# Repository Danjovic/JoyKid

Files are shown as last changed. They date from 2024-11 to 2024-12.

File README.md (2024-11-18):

# Joy Kid 

This project started as an exercise of passing and receiving parameters using CALL function, but evolved to a hardware prototype using a microcontroller that sends data through the MSX joystick port in order to emulate the MSX  [Sensor Kid](https://www.msx.org/wiki/Micomsoft_Sensor_Kid) Interface.

## Protocol
The circuit uses lightweight protocol that transfers sensor data using nibbles. The transfer is commanded by pin 8 (pulse) and the data transfer is paced by pin 7 (trigger B). Pin 6 (trigger A) is used both by the microcontroller to provide a 'ready' signal to the MSX and also to get PORT0/1 data. 

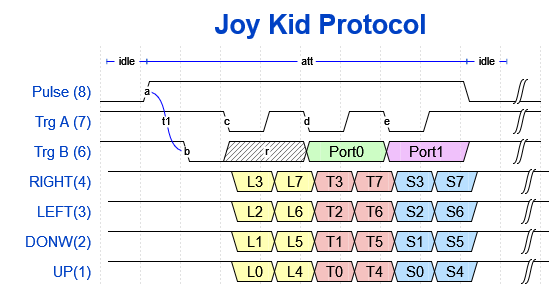
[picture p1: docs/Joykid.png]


### Waveform

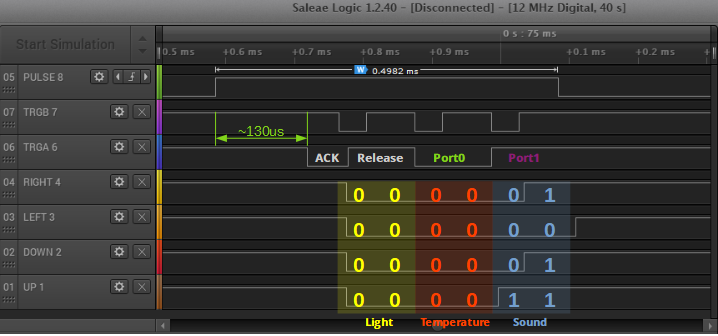
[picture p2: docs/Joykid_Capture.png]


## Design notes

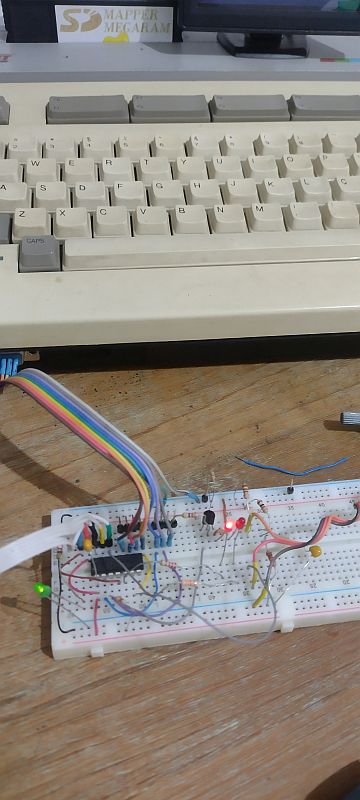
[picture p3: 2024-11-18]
docs/prototype0.jpg

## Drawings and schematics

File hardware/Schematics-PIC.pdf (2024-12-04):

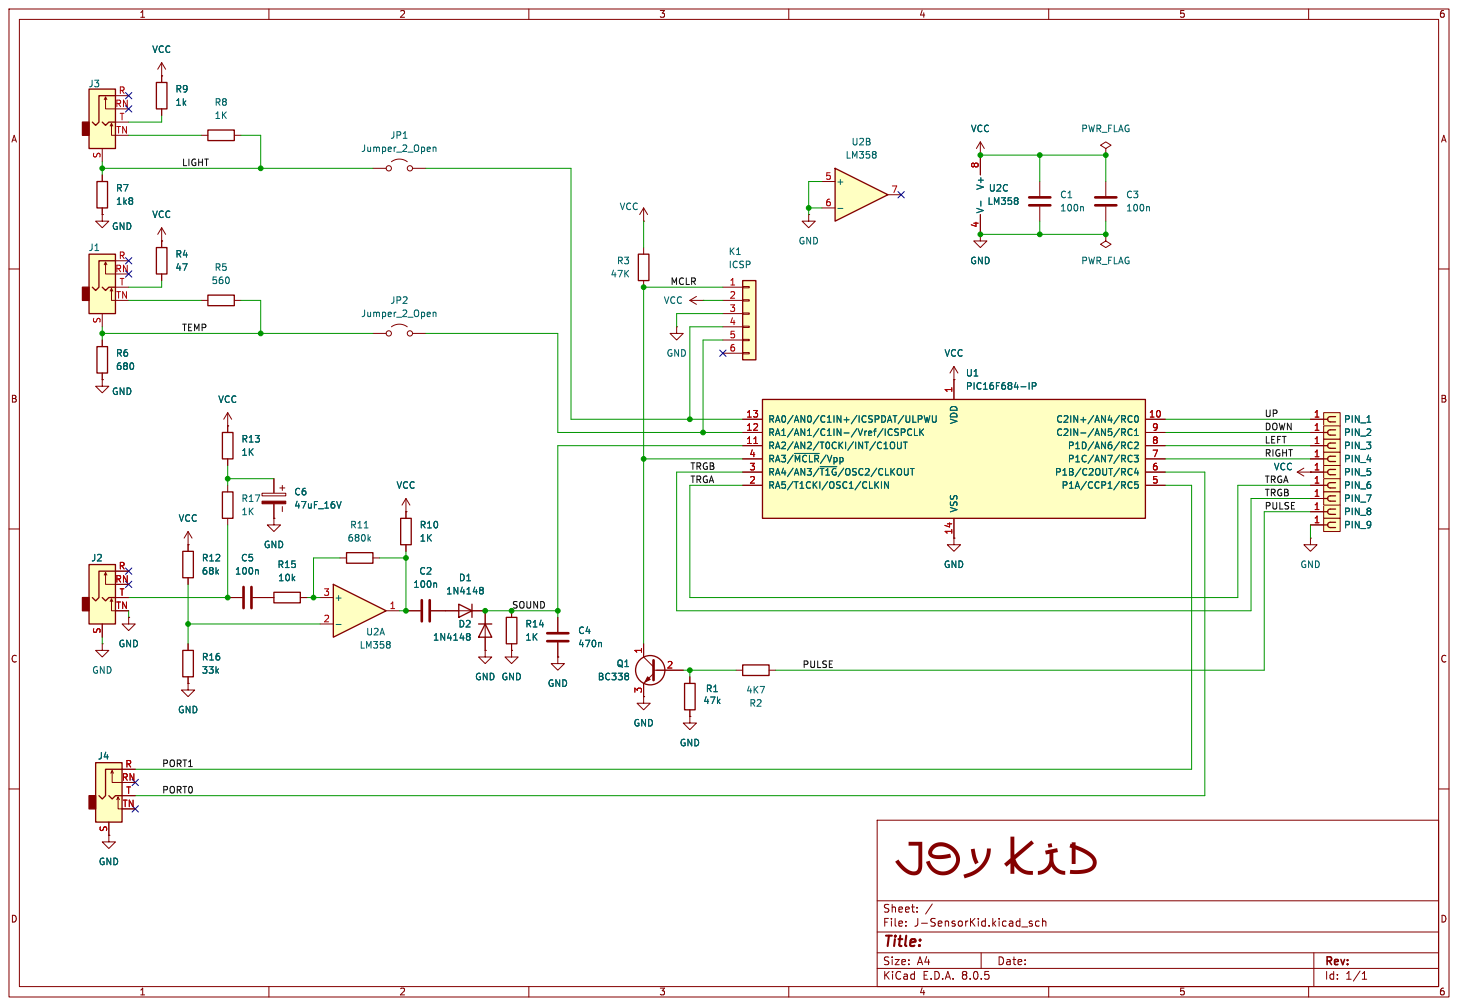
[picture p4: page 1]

1 C2IN+/AN4/RC0 10 RA2/AN2/T0CKI/INT/C1OUT 11 RA1/AN1/C1IN-/Vref/ICSPCLK 12 RA0/AN0/C1IN+/ICSPDAT/ULPWU 13 VSS 14 RA5/T1CKI/OSC1/CLKIN 2 RA4/AN3/~{T1G}/OSC2/CLKOUT 3 RA3/~{MCLR}/Vpp 4 P1A/CCP1/RC5 5 P1B/C2OUT/RC4 6 P1C/AN7/RC3 7 P1D/AN6/RC2 8 C2IN-/AN5/RC1 9 U1PIC16F684-IP GND GND
1K GND

1 C2IN+/AN4/RC0 10 RA2/AN2/T0CKI/INT/C1OUT 11 RA1/AN1/C1IN-/Vref/ICSPCLK 12 RA0/AN0/C1IN+/ICSPDAT/ULPWU 13 VSS 14 RA5/T1CKI/OSC1/CLKIN 2 RA4/AN3/~{T1G}/OSC2/CLKOUT 3 RA3/~{MCLR}/Vpp 4 P1A/CCP1/RC5 5 P1B/C2OUT/RC4 6 P1C/AN7/RC3 7 P1D/AN6/RC2 8 C2IN-/AN5/RC1 9 GND

LEFT RIGHT DOWN JOY KID

Id: 1/1 Title: File: J-SensorKid.kicad_sch Sheet: /

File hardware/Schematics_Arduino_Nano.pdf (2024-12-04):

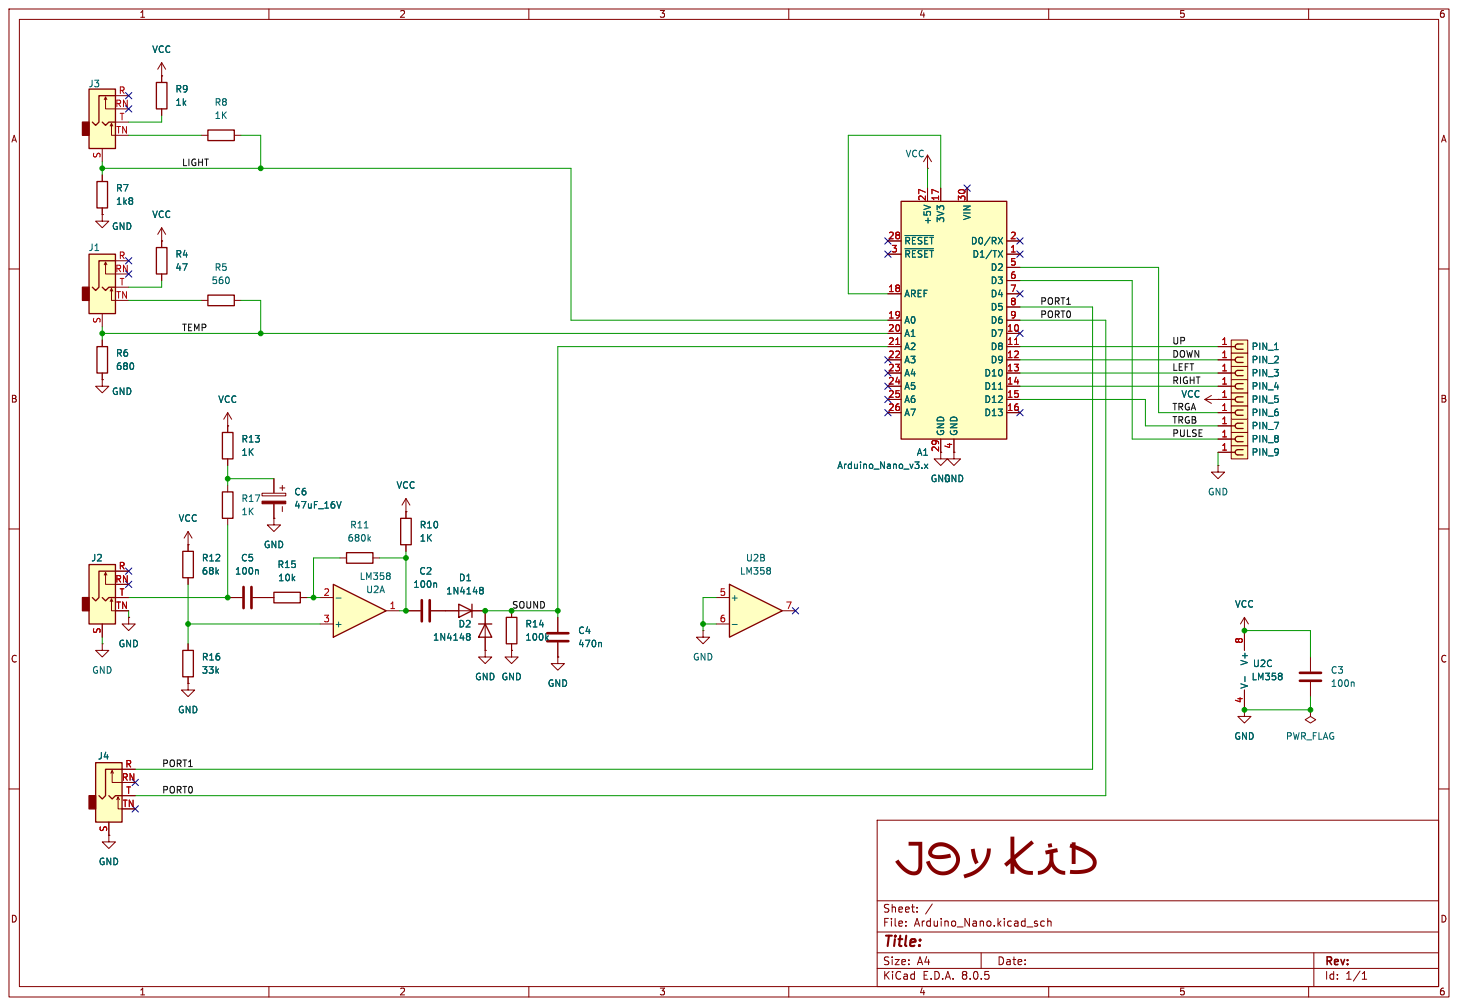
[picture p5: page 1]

Id: 1/1 Title: File: Arduino_Nano.kicad_sch Sheet: / GND

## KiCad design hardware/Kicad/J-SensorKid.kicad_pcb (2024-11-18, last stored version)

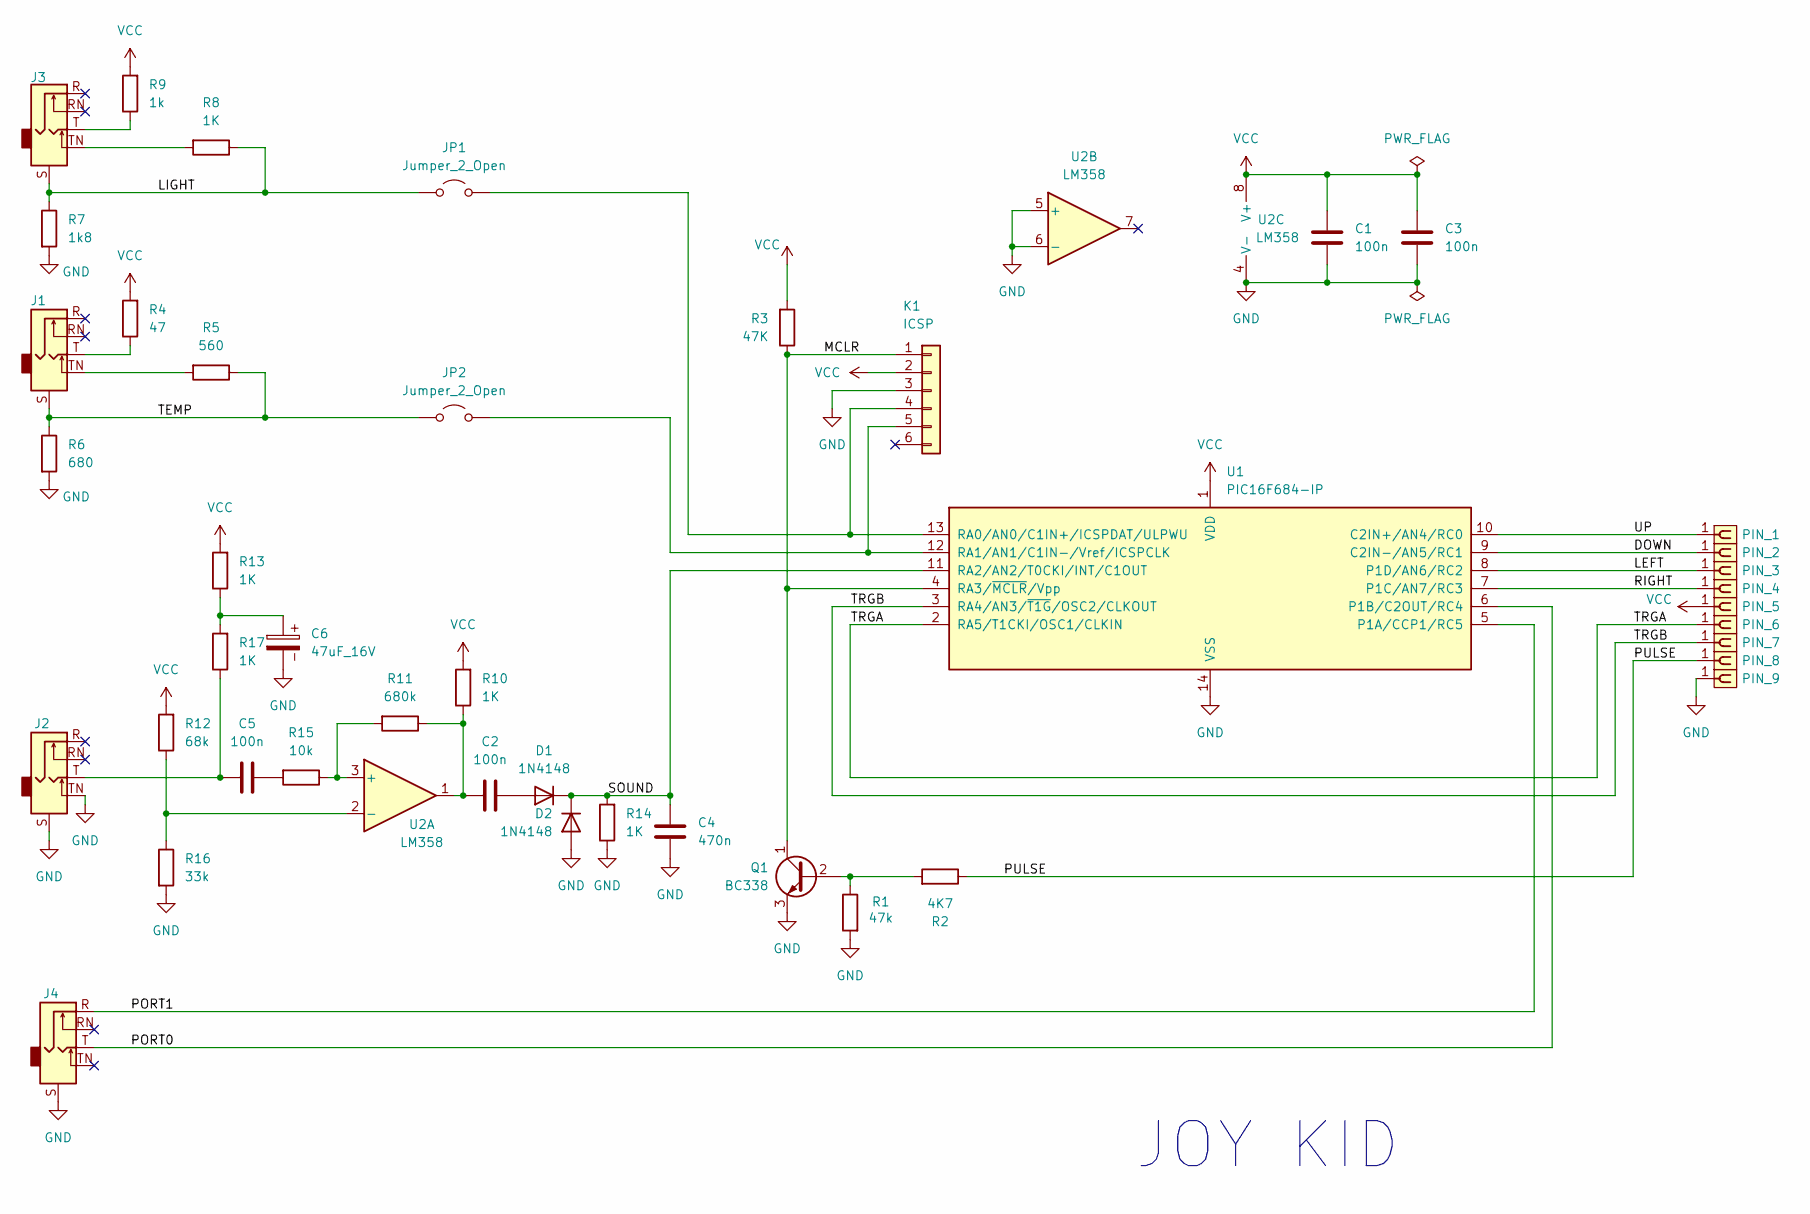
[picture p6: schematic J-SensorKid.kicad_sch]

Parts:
C1, C2, C3, C5: 100n; C_Disc_D6.0mm_W2.5mm_P5.00mm
C4: 470n; C_Disc_D6.0mm_W4.4mm_P5.00mm
C6: 47uF_16V; CP_Radial_D5.0mm_P2.00mm
D1, D2: 1N4148; D_DO-35_SOD27_P7.62mm_Horizontal
J1, J2, J3, J4: AudioJack2_Ground_Switch; Jack_3.5mm_CUI_SJ1-3535NG_Horizontal
JP1, JP2: Jumper_2_Open; PinHeader_1x02_P2.54mm_Vertical
K1: ICSP; PinHeader_1x06_P2.54mm_Vertical
PIN_1, PIN_2, PIN_3, PIN_4, PIN_5, PIN_6, PIN_7, PIN_8, PIN_9: PINHD_1x1_Female; PinSocket_1x01_P2.54mm_Vertical
Q1: BC338; TO-92L
R1: 47k; R_Axial_DIN0204_L3.6mm_D1.6mm_P7.62mm_Horizontal
R2: 4K7; R_Axial_DIN0204_L3.6mm_D1.6mm_P7.62mm_Horizontal
R3: 47K; R_Axial_DIN0204_L3.6mm_D1.6mm_P7.62mm_Horizontal
R4: 47; R_Axial_DIN0204_L3.6mm_D1.6mm_P7.62mm_Horizontal
R5: 560; R_Axial_DIN0204_L3.6mm_D1.6mm_P7.62mm_Horizontal
R6: 680; R_Axial_DIN0204_L3.6mm_D1.6mm_P7.62mm_Horizontal
R7: 1k8; R_Axial_DIN0204_L3.6mm_D1.6mm_P7.62mm_Horizontal
R8, R10, R13, R14, R17: 1K; R_Axial_DIN0204_L3.6mm_D1.6mm_P7.62mm_Horizontal
R9: 1k; R_Axial_DIN0204_L3.6mm_D1.6mm_P7.62mm_Horizontal
R11: 680k; R_Axial_DIN0204_L3.6mm_D1.6mm_P7.62mm_Horizontal
R12: 68k; R_Axial_DIN0204_L3.6mm_D1.6mm_P7.62mm_Horizontal
R15: 10k; R_Axial_DIN0204_L3.6mm_D1.6mm_P7.62mm_Horizontal
R16: 33k; R_Axial_DIN0204_L3.6mm_D1.6mm_P7.62mm_Horizontal
U1: PIC16F684-IP; DIP-14_W7.62mm
U2: LM358; DIP-8_W7.62mm

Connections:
/DOWN: PIN_2.1, U1.9 (C2IN-/AN5/RC1)
/LEFT: PIN_3.1, U1.8 (P1D/AN6/RC2)
/LIGHT: J3.S, JP1.1 (A), R7.1, R8.1
/MCLR: K1.1, Q1.1 (C), R3.1, U1.4 (RA3/~MCLR/Vpp)
/PORT0: J4.T, U1.6 (P1B/C2OUT/RC4)
/PORT1: J4.R, U1.5 (P1A/CCP1/RC5)
/PULSE: PIN_8.1, R2.1
/RIGHT: PIN_4.1, U1.7 (P1C/AN7/RC3)
/SOUND: C4.2, D1.1 (K), D2.1 (K), R14.2, U1.11 (RA2/AN2/T0CKI/INT/C1OUT)
/TEMP: J1.S, JP2.1 (A), R5.1, R6.1
/TRGA: PIN_6.1, U1.2 (RA5/T1CKI/OSC1/CLKIN)
/TRGB: PIN_7.1, U1.3 (RA4/AN3/~T1G/OSC2/CLKOUT)
/UP: PIN_1.1, U1.10 (C2IN+/AN4/RC0)
GND: C1.2, C3.2, C4.1, C6.2, D2.2 (A), J2.S, J2.TN, J4.S, K1.3, PIN_9.1, Q1.3 (E), R1.2, R6.2, R7.2, R14.1, R16.2, U1.14 (VSS), U2.4 (V-), U2.5 (+), U2.6 (-)
unnamed: C2.1, R10.1, R11.1, U2.1
unnamed: C5.1, J2.T, R17.1
unnamed: C5.2, R15.2
unnamed: C6.1, R13.1, R17.2
unnamed: C2.2, D1.2 (A)
unnamed: J1.T, R4.1
unnamed: J1.TN, R5.2
unnamed: J3.T, R9.1
unnamed: J3.TN, R8.2
unnamed: JP1.2 (B), K1.4, U1.13 (RA0/AN0/C1IN+/ICSPDAT/ULPWU)
unnamed: JP2.2 (B), K1.5, U1.12 (RA1/AN1/C1IN-/Vref/ICSPCLK)
unnamed: Q1.2 (B), R1.1, R2.2
unnamed: R11.2, R15.1, U2.3 (+)
unnamed: R12.1, R16.1, U2.2 (-)
VCC: C1.1, C3.1, K1.2, PIN_5.1, R3.2, R4.2, R9.2, R10.2, R12.2, R13.2, U1.1 (VDD), U2.8 (V+)

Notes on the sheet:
JOY KID

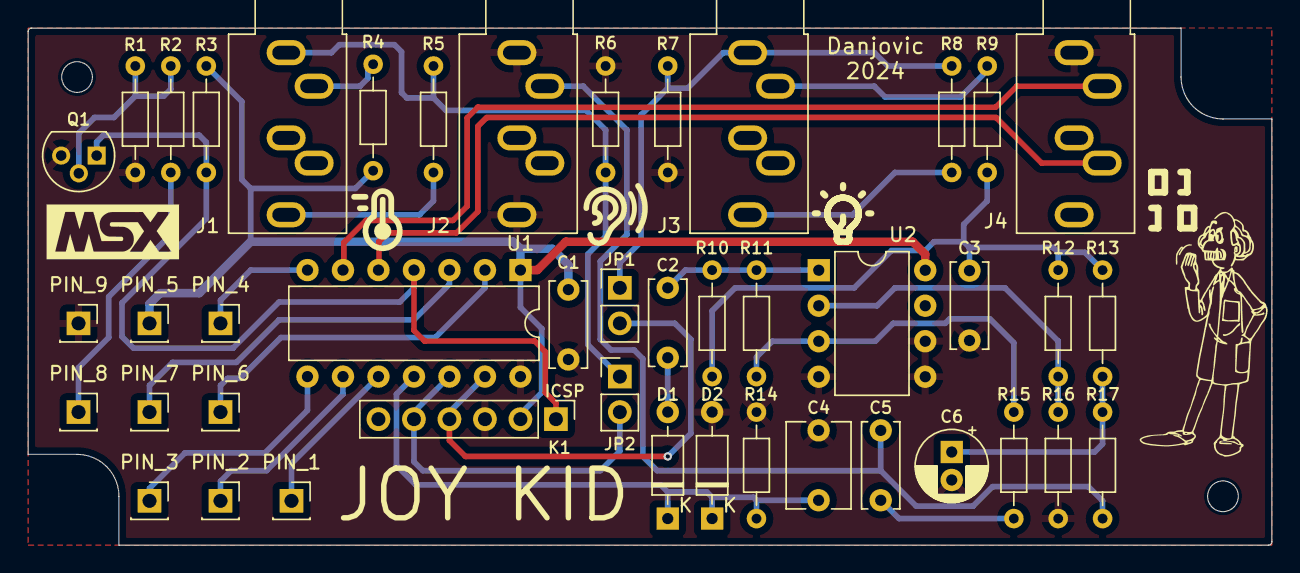
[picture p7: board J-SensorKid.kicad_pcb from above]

Board: 2 copper layers, 89.0 x 37.0 mm, 47 parts (0 on the bottom side), 29 nets.

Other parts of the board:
MH1, MH2: MountingHole_2.2mm_M2_DIN965
PCB1: PB-082_1

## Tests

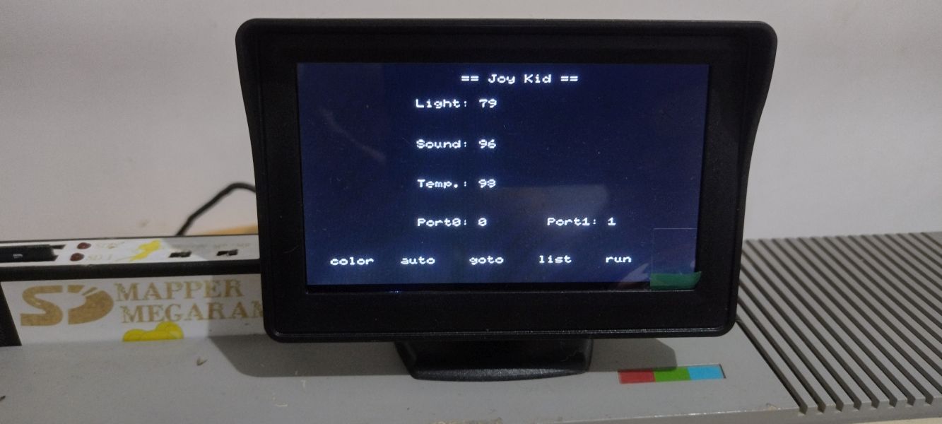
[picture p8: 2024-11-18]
docs/testProgram.jpg

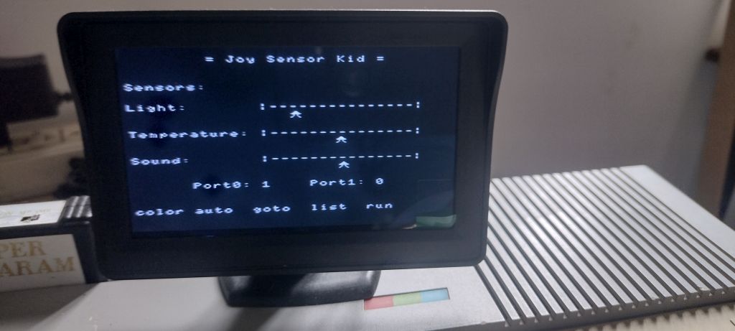
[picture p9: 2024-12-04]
docs/testProgram1.jpg

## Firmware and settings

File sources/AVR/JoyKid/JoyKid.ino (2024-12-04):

/*.
     ____.              ____  __.__    .___
    |    | ____ ___.__.|    |/ _|__| __| _/
    |    |/  _ <   |  ||      < |  |/ __ | 
/\__|    (  <_> )___  ||    |  \|  / /_/ | 
\________|\____// ____||____|__ \__\____ | 
                \/             \/       \/ 
  Sensor Kid for the Joystick port 
  Danjovic 2024 
*/


/* JoyKid Protocol

 GETTING ATTENTION
 - MSX rise pin 8 to marks the beginning of a transfer and wait for the JoyKid to acknowledge by lowering pin 6 
 - Joykid regognizes the ATT request, reads the values of its analog sensors and then drop pin 6 
 
 Now both MSX and JoyKid are ready to TRANSFERING DATA 
 
 - MSX drops pin 7 to mark the start of a data frame.
 - JoyKid recognize the sof mark, writes 1st lower nibble and release pin 6
 - MSX reads the 1st lower nibble, then rise pin 7
 
 - Joykid recognize the change and write the 1st higher nibble
 - MSX reads the 1st higher nibble, then drop pin 7 and write PORT0 value 
 - Joykid recognize the change, read PORT0 value and and write the 2nd lower nibble
 - MSX reads the 2nd lower nibble, then rise pin 7
 - Joykid recognize the change and write the 2nd higher nibble
 - MSX reads the 1st higher nibble, then drop pin 7 and write PORT1 value 
 - Joykid recognize the change, read PORT1 value and and write the 3rd lower nibble
 - MSX reads the 3rd lower nibble, then rise pin 7
 - Joykid recognize the change and write the 3rd higher nibble
 - MSX reads the 3rd higher nibble, then drop pin 8 to finalize the transfer
 - Joykid recognize the change, release the data lines populate the outputs and wait for the start of a new transfer
 
 
 
 
; Protocol
;        ____________________________________________
;  8 ___/ ATT                                        \_______
;    ________________        ____      ____      ____________
;  7                 \_sof__/    \____/    \____/           
;    _________         __________                     _______ 
;  6          \_ack___/ release  |  PORT 0 |  PORT 1 |
;    
;  1 ------------------| d0 | d4 | d0 | d4 | d0 | d4 |-------
;  2 ------------------| d1 | d5 | d1 | d4 | d5 | d5 |-------
;  3 ------------------| d2 | d6 | d2 | d4 | d6 | d6 |-------
;  4 ------------------| d3 | d7 | d3 | d4 | d7 | d7 |-------
;
*/


//    _ _ _                 _
//   | (_) |__ _ _ __ _ _ _(_)___ ___
//   | | | '_ \ '_/ _` | '_| / -_|_-<
//   |_|_|_.__/_| \__,_|_| |_\___/__/
//
#include "stdbool.h"

//         _               _
//    _ __(_)_ _  ___ _  _| |_
//   | '_ \ | ' \/ _ \ || |  _|
//   | .__/_|_||_\___/\_,_|\__|
//   |_|

//                Arduino Nano
//                    ____
//               +---|    |---+
//               |O  |____|  O|
//              =|D13      D12|= MSX TRG B  7
//  +--[100R]-- =|3V3      D11|= MSX RIGHT  4
//  +---------- =|VREF     D10|= MSX LEFT   3
// Light Sensor =|A0/D14    D9|= MSX DOWN   2
// Temp. Sensor =|A1/D15    D8|= MSX UP     1
// Sound Sensor =|A2/D16    D7|=
//              =|A3/D17    D6|= PORT1
//              =|A4/D18    D5|= PORT0
//              =|A5/D19    D4|=
//              =|A6/D20    D3|= MSX TRG A  6
//              =|A7/D21    D2|= MSX PULSE  8
//    MSX VCC 5 =|5V       GND|= MSX GND    9
//              =|RST      RST|=
//              =|GND       RX|=
//              =|V1N       TX|=
//               |O          O|
//               +------------+
//




//       _      __ _      _ _   _
//    __| |___ / _(_)_ _ (_) |_(_)___ _ _  ___
//   / _` / -_)  _| | ' \| |  _| / _ \ ' \(_-<
//   \__,_\___|_| |_|_||_|_|\__|_\___/_||_/__/
//

// port B
#define MSXup 0        //
#define MSXdown 1      //
#define MSXleft 2      //
#define MSXright 3     //
#define MSXtriggerB 4  //

//  port C
#define LIGHT_CHANNEL A0  //
#define TEMP_CHANNEL A1   //
#define SOUND_CHANNEL A2  //

//  port D
#define MSXpulse 2     //
#define MSXtriggerA 3  //
#define PORT_0 6      //
#define PORT_1 5       //


// Registers associated with pins

#define PIN_PIN6 PIND
#define DDR_PIN6 DDRD
#define PORT_PIN6 PORTD

#define PIN_PIN7 PINB
#define DDR_PIN7 DDRB
#define PORT_PIN7 PORTB

#define PIN_PIN8 PIND
#define DDR_PIN8 DDRD
#define PORT_PIN8 PORTD


#define PIN_PIN1TO4 PINB
#define DDR_PIN1TO4 DDRB
#define PORT_PIN1TO4 PORTB


//
//    _ __  __ _ __ _ _ ___ ___
//   | '  \/ _` / _| '_/ _ (_-<
//   |_|_|_\__,_\__|_| \___/__/
//
#define Pin8isLow() (PIN_PIN8 & (1 << MSXpulse)) == 0
#define Pin8isHigh() (PIN_PIN8 & (1 << MSXpulse)) != 0

#define Pin7isLow() (PIN_PIN7 & (1 << MSXtriggerB)) == 0
#define Pin7isHigh() (PIN_PIN7 & (1 << MSXtriggerB)) != 0

#define Pin6isLow() (PIN_PIN6 & (1 << MSXtriggerA)) == 0
#define Pin6isHigh() (PIN_PIN6 & (1 << MSXtriggerA)) != 0

//#define Pin8()   PIN_PIN8&(1<<MSXpulse)!=0    // get the state of pin 8
//#define Pin7()   PIN_PIN7&(1<<MSXtriggerB)!=0    // get the state of pin 8
//#define Pin6()   PIN_PIN6&(1<<MSXtriggerA)!=0    // get the state of pin 8


#define DropPin6() DDRD |= (1 << MSXtriggerA)
#define ReleasePin6() DDRD &= ~(1 << MSXtriggerA)
#define ReleaseOutputs() DDRB &= ~((1 << MSXup) | (1 << MSXdown) | (1 << MSXleft) | (1 << MSXright))


//                 _      _    _
//   __ ____ _ _ _(_)__ _| |__| |___ ___
//   \ V / _` | '_| / _` | '_ \ / -_|_-<
//    \_/\__,_|_| |_\__,_|_.__/_\___/__/
//
bool Port0, Port1;
uint8_t lightSensor, temperatureSensor, soundSensor;

//                 _       _
//    _ __ _ _ ___| |_ ___| |_ _  _ _ __  ___ ___
//   | '_ \ '_/ _ \  _/ _ \  _| || | '_ \/ -_|_-<
//   | .__/_| \___/\__\___/\__|\_, | .__/\___/__/
//   |_|                       |__/|_|

void transferData(void);

//               _
//    _ __  __ _(_)_ _
//   | '  \/ _` | | ' \ 
//   |_|_|_\__,_|_|_||_|
//


void setup() {
  Serial.begin(115200);
  // initialize pins
  pinMode(MSXup, INPUT);        //
  pinMode(MSXdown, INPUT);      //
  pinMode(MSXleft, INPUT);      //
  pinMode(MSXright, INPUT);     //
  pinMode(MSXtriggerB, INPUT);  //
  pinMode(MSXtriggerA, INPUT);  //
  pinMode(PORT_0, OUTPUT);      //
  pinMode(PORT_1, OUTPUT);      //

  digitalWrite(MSXup, LOW);        // No pull-ups, use MSX internal pullups
  digitalWrite(MSXdown, LOW);      //
  digitalWrite(MSXleft, LOW);      //
  digitalWrite(MSXright, LOW);     //
  digitalWrite(MSXtriggerB, LOW);  //
  digitalWrite(MSXtriggerA, LOW);  //
  digitalWrite(PORT_0, LOW);       // Powerup state
  digitalWrite(PORT_1, LOW);       // Powerup state

  //analogReference(EXTERNAL);   // required for the sound amplifier
  ReleasePin6();
  Serial.print("wait...");
  // wait initially for Pin8 be unactive
  while (Pin8isHigh()) {};
  Serial.println("Go!");
}

void loop() {
  // - MSX rise pin 8 to marks the beginning of a transfer
  // - Joykid regognizes the ATT request, ...
  while (Pin8isLow()) {};  // wait for the ATT
  transferData();
  ReleasePin6();
  ReleaseOutputs();
  //    Serial.print("@");
}



void transferData(void) {
  cli();
  volatile uint8_t tempDDR = DDR_PIN1TO4 & ~((1 << MSXup) | (1 << MSXdown) | (1 << MSXleft) | (1 << MSXright));
  // ..., reads the values of its analog sensors and then drop pin 6
  // Read ADC values ( ~130us to read the three channels )
  lightSensor = analogRead(LIGHT_CHANNEL) >> 2;
  temperatureSensor = analogRead(TEMP_CHANNEL) >> 2;
  soundSensor = analogRead(SOUND_CHANNEL) >> 2;
  DropPin6();

  // - MSX drops pin 7 to mark the start of a data frame.
  // - JoyKid recognize the sof mark, writes 1st lower nibble and release pin 6
  while (Pin7isHigh()) { if (Pin8isLow()) return; };
  DDR_PIN1TO4 = (tempDDR | (~lightSensor & 0x0f));  // invert the bits to write to DDR
  ReleasePin6();


  // - MSX reads the 1st lower nibble, then rise pin 7
  // - Joykid recognize the change and write the 1st higher nibble
  while (Pin7isLow()) { if (Pin8isLow()) return; };
  DDR_PIN1TO4 = (tempDDR | ((~lightSensor >> 4) & 0x0f));

  // - MSX reads the 1st higher nibble, then drop pin 7 and write PORT0 value
  // - Joykid recognize the change, read PORT0 value and and write the 2nd lower nibble
  while (Pin7isHigh()) { if (Pin8isLow()) return; };
  DDR_PIN1TO4 = (tempDDR | (~temperatureSensor & 0x0f));
  Port0 = (Pin6isHigh() ? true : false);


  // - MSX reads the 2nd lower nibble, then rise pin 7
  // - Joykid recognize the change and write the 2nd higher nibble
  while (Pin7isLow()) { if (Pin8isLow()) return; };
  DDR_PIN1TO4 = (tempDDR | ((~temperatureSensor >> 4) & 0x0f));


  // - MSX reads the 1st higher nibble, then drop pin 7 and write PORT1 value
  // - Joykid recognize the change, read PORT1 value and and write the 3rd lower nibble
  while (Pin7isHigh()) { if (Pin8isLow()) return; };
  DDR_PIN1TO4 = (tempDDR | (~soundSensor & 0x0f));
  Port1 = (Pin6isHigh() ? true : false);


  // - MSX reads the 3rd lower nibble, then rise pin 7
  // - Joykid recognize the change and write the 3rd higher nibble
  while (Pin7isLow()) { if (Pin8isLow()) return; };
  DDR_PIN1TO4 = (tempDDR | ((~soundSensor >> 4) & 0x0f));


  // - MSX reads the 3rd higher nibble, then drop pin 8 to finalize the transfer
  // - Joykid recognize the change, release the data lines populate the outputs and wait for the start of a new transfer
  while (Pin8isHigh()) {};  // wait pin 8 to fall, data lines released right after return
  digitalWrite(PORT_0, Port0);
  digitalWrite(PORT_1, Port1);
  sei();
  //    Serial.print("%");
  //
}

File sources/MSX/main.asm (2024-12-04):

; 
;      ____.              ____  __.__    .___
;     |    | ____ ___.__.|    |/ _|__| __| _/
;     |    |/  _ <   |  ||      < |  |/ __ | 
; /\__|    (  <_> )___  ||    |  \|  / /_/ | 
; \________|\____// ____||____|__ \__\____ | 
;                 \/             \/       \/ 
;   Sensor Kid for the Joystick port 
;   Danjovic 2024 
; 
; Protocol
;      ____________________________________________
; 8___/ ATT                                        \_______
;  ________________        ____      ____      ____________
; 7                \_sof__/    \____/    \____/           
;  _________         __________                     _______ 
; 6         \_ack___/ release  |  PORT 0 |  PORT 1 |
;
; 1------------------| d0 | d4 | d0 | d4 | d0 | d4 |-------
; 2------------------| d1 | d5 | d1 | d4 | d5 | d5 |-------
; 3------------------| d2 | d6 | d2 | d4 | d6 | d6 |-------
; 4------------------| d3 | d7 | d3 | d4 | d7 | d7 |-------
;
;  MSX: 
;  1 issue ATT (pin 8 high)
;  2 wait for ack. If timeout, goto step 17     
;  3 drop clock (pin 7 low, SOF)
;  4 read lower nibble
;  5 rise clock (pin 7)
;  6 read higher nibble 
;
;  7 write PORT0 value
;  8-11 repeat steps 3..6
; 
;  12 write PORT1 value
;  13-16 repeat steps 3..6
;
;  17 drop pin 8, rise pins 6 and 7 







;  ___         _                            _      _    _        
; / __|_  _ __| |_ ___ _ __   __ ____ _ _ _(_)__ _| |__| |___ ___
; \__ \ || (_-<  _/ -_) '  \  \ V / _` | '_| / _` | '_ \ / -_|_-<
; |___/\_, /__/\__\___|_|_|_|  \_/\__,_|_| |_\__,_|_.__/_\___/__/
;      |__/                                                      
; 
;INCLUDE "msx_system_vars.inc"
SLTATR: EQU 0FCC9H
PROCNM: EQU 0FD89H 
VALTYP: EQU 0F663H
RS2IQ:  equ 0FAF5H

; Sensor and port variables stored at unused rs232 queue
PORTVALUE: EQU RS2IQ
LIGHTVALUE: EQU RS2IQ+1
TEMPERATUREVALUE: EQU RS2IQ+2
SOUNDVALUE: EQU RS2IQ+3


;  ___ ___ ___  ___           _ _    
; | _ )_ _/ _ \/ __|  __ __ _| | |___
; | _ \| | (_) \__ \ / _/ _` | | (_-<
; |___/___\___/|___/ \__\__,_|_|_/__/
;                                    
; 
CALBAS : EQU 0159H
CHPUT:   EQU 00A2H
CHRGTR : EQU 0010H

;  ___   _   ___ ___ ___    __              _   _             
; | _ ) /_\ / __|_ _/ __|  / _|_  _ _ _  __| |_(_)___ _ _  ___
; | _ \/ _ \\__ \| | (__  |  _| || | ' \/ _|  _| / _ \ ' \(_-<
; |___/_/ \_\___/___\___| |_|  \_,_|_||_\__|\__|_\___/_||_/__/
;                                                             
; 
FRMEVL:  EQU 4C64h
FRESTR:  EQU 67D0h
ERRHAND: EQU 406FH
PTRGET:  EQU 5EA4h
CHKALF:  EQU 64A7h  ; check for uppercase
GETBYT:  EQU 521Ch  ; evaluate expression into a byte
DIOERR:  EQU 73B2H	; device i/o error	

;  ___ _            _   
; / __| |_ __ _ _ _| |_ 
; \__ \  _/ _` | '_|  _|
; |___/\__\__,_|_|  \__|
;                       

ORG 0c004h

START:

    ; Call handler pointer in Bank 3 fixed offset 4
    DW CALLHAND


    LD A,(#F344) ; SlotID of RAM in Bank 3 (#C000-#FFFF)
    ; This variable is ready available only when disk drive is present.
    AND A
    JP M,.SKIP   ; SlotID has SubSlot information
    AND 3
.SKIP
    AND 15
    LD E,A
    RLCA
    RLCA
    RLCA
    RLCA
    OR E
    AND 60
    LD D,0
    LD E,A
    LD HL,SLTATR+3 ; +3 for Bank 3
    ADD HL,DE
    SET 5,(HL)     ; Set bit 5 to enable CALL handler
    RET
 

; Handle for the CALL Command

CALLHAND:
 
    PUSH    HL
    LD    HL,CMDS            ; Table with "_" instructions
.CHKCMD:
    LD    DE,PROCNM
.LOOP:    LD    A,(DE)
    CP    (HL)
    JR    NZ,.TONEXTCMD    ; Not equal
    INC    DE
    INC    HL
    AND    A
    JR    NZ,.LOOP    ; No end of instruction name, go checking
    LD    E,(HL)
    INC    HL
    LD    D,(HL)
    POP    HL        ; routine address
    CALL    GETPREVCHAR
    CALL    .CALLDE        ; Call routine
    AND    A
    RET
 
.TONEXTCMD:
    LD    C,0FFH
    XOR    A
    CPIR            ; Skip to end of instruction name
    INC    HL
    INC    HL        ; Skip address
    CP    (HL)
    JR    NZ,.CHKCMD    ; Not end of table, go checking
    POP    HL
        SCF
    RET
 
.CALLDE:
    PUSH    DE
    RET
 
;---------------------------
CMDS:
 
; List of available instructions (as ASCIIZ) and execute address (as word)
    DEFB    "LIGHT",0
	DEFW    _LIGHT
   
    DEFB    "TEMP",0
	DEFW    _TEMP
	
	DEFB    "HEAR",0
	DEFW    _HEAR
   
	DEFB    "PORT0",0
	DEFW    _PORT0

	DEFB    "PORT1",0
	DEFW    _PORT1
   
 
    DEFB    0               ; No more instructions
 
;---------------------------

_PORT0:
   CALL EVALPARAM
   LD A,E
   OR A              ; test for zero
   LD A,(PORTVALUE)
   RES 0,A           ; reset bit
   JR Z,$+4          ; is it zero
   SET 0,A           ; no, clear relevant bit
   JR PORTCOMMON

   
_PORT1:
   CALL EVALPARAM
   LD A,E
   OR A              ; test for zero
   LD A,(PORTVALUE)
   RES 1,A           ; reset bit
   JR Z,$+4          ; is it zero
   SET 1,A           ; no, set relevant bit
   
PORTCOMMON:
   LD (PORTVALUE),A
   CALL TRANSFER
     ; TODO check for carry (interface timed out)
     LD    IX,DIOERR    ; Device I/O error
     JP c, CALBAS
   RET
   


_LIGHT:
    CALL EVALINTPARAM
	push de
	CALL TRANSFER
	LD A,(LIGHTVALUE)
	JR SENSORCOMMON
	
_TEMP:
    CALL EVALINTPARAM
	push de
	CALL TRANSFER
	LD A,(TEMPERATUREVALUE)
	JR SENSORCOMMON
	
_HEAR:
    CALL EVALINTPARAM
	push de
	CALL TRANSFER
	LD A,(SOUNDVALUE)
;	JR SENSORCOMMON
		

	
SENSORCOMMON:
    pop de
	; TODO check for carry (interface timed out)
       LD    IX,DIOERR    ; Device I/O error
       JP c, CALBAS   	
	LD (DE),A
	LD A,0
	OR A
	RET
	

EVALPARAM:
    ; check opening '('   
    CALL CHKCHAR   
    DB '('

    ; evaluate its value into a byte
    PUSH HL	
    LD IX,GETBYT  ; 64A7H 
    CALL CALBAS
    POP HL
    inc hl
    ; check ending ')' 
    CALL CHKCHAR
    DB ')'
    RET
	
EVALINTPARAM:
    ; check opening '('   
    CALL CHKCHAR   
    DB '('
	
    ; check if it is a variable
    PUSH HL
    LD IX,CHKALF  ; 64A7H 
    CALL CALBAS
    POP HL
    JP C,TYPE_MISMATCH    

    ; evaluate variable and get its type
    PUSH HL
    LD IX,FRMEVL ; 4C64H
    CALL CALBAS
    POP HL
    
    ; check variable type. 
    LD A,(VALTYP)   
    CP 2        ; is it integer ?
    JP NZ,TYPE_MISMATCH ; no, error

    ; get variable address (in DE)
    LD IX, PTRGET ;  5EA4h
    CALL CALBAS
    
    ; check ending ')' 
    CALL CHKCHAR
    DB ')'
    RET

 
CHKCHAR:
    CALL    GETPREVCHAR    ; Get previous basic char
    EX    (SP),HL
    CP    (HL)             ; Check if good char
    JR    NZ,SYNTAX_ERROR    ; No, Syntax error
    INC    HL
    EX    (SP),HL
    INC    HL        ; Get next basic char
 
GETPREVCHAR:
    DEC    HL
    LD    IX,CHRGTR
    JP      CALBAS
 
 
TYPE_MISMATCH:
        LD      E,13
        DB      1
 
SYNTAX_ERROR:
        LD      E,2
    LD    IX,ERRHAND    ; Call the Basic error handler
    JP    CALBAS


TRANSFER:
ld de,PORTVALUE ; first address of data buffer
zz0:
INCLUDE "joykid_drivers.asm"
zz1:
